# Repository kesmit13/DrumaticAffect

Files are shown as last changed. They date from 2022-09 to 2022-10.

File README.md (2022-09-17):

# Drumatic Affect

The circuit and program described in this project are used to add features to the 
[Digitech SDRUM](https://www.digitech.com/band-creator/SDRUM.html)
pedal, which is a drum machine that has a lot of cool features but seems to be missing some
key functionality for my purposes. The main thing that it is missing is a way to specify
a specific beats per minute. The use cases for the design of the pedal seem to be to use tap
tempo to set the tempo, or to set the tempo when a song is programmed.

I intend to use the pedal to drive the tempo of the song, but I don't program the song slots
with specific songs. Each song slot merely has various beats programmed that can be used in 
various songs. I simply select the set of verse / chorus / bridge beats that work the best for
a song, then set the proper tempo for the song, and start it. I want to be able to set a 
specific tempo that I've determined ahead of time so that the SDRUM unit can keep that exact
tempo rather than setting one on-the-fly with the tap tempo.

Unfortunately, this is the one thing that the SDRUM unit can't do. There is no way to know or set
the exact tempo. You can get in-the-ballpark by using a metronome to set a tempo then trying to
tap that tempo, but it's somewhat in-exact.

The idea came about to have a hardware device send the tap signal rather than a person. This would
give a very exact tempo that could be set simply be dialing in the correct tempo on the device
and having it send emulated taps to the footswitch input. That device is the **Drumatic Affect**.
I came across [another project](https://www.instructables.com/Arduino-Metronome/) that had some 
overlap, started with that and continued to modify it until it fit the new purpose.

## Requirements

I had a pretty long list of requirements for a drum machine that would fit my needs. I tried out
many different solutions and nothing existed that could do everything I wanted. Here is a 
comparison table of many possible solutions.

| Feature | SDRUM + Drumatic Affect | SDRUM | Rock Drummer App | Beat Buddy | Alesis SR-16 | Drum Tracks |
|---|---|---|---|---|---|---|
| Battery powered | yes* | yes*  | yes | yes* | yes* | yes |
| Song selector in arm's reach | yes (with stand) | no* | yes (with stand) | no | yes (with stand) | yes |
| Able to set specific tempo | yes | no | yes | yes | yes | yes |
| Direct access to song parts | yes | yes*  | yes/no | no | yes (only 2) | no |
| Start and stop with footswitch | yes | no* | yes | yes | yes | yes |
| Fills | yes | yes | yes | yes | yes | no |
| Easily programmable | yes | yes | no | yes | no | no |
| Programs beat patterns not just songs | yes | yes | yes | no | yes | no |
| Fast setup at gigs | yes | yes | no | yes | yes | yes |
| Count-in | yes | yes | yes | yes | no | yes |
| Mute on-demand | yes | yes | no | no | no | no |

Some of the requirements are marked with exceptions. Such as the battery powered requirement can be filled 
with a 9v guitar effect pedal battery pack on most devices. The SDRUM does have many of the requirements, 
but some can not be filled at the same time depending on which footswitch mode you use.

## Schematic

The schematic for the Drumatic Affect device is shown below.

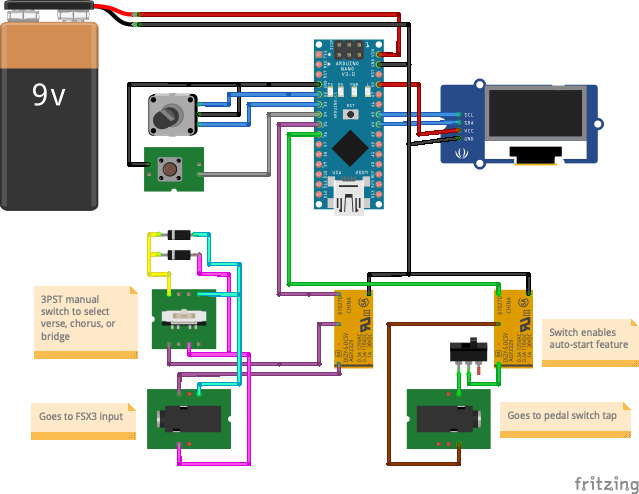
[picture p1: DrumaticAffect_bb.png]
Schematic diagram


This circuit includes two relays driven by an Arduino Nano and the code in this repository.
The first relay is used to send the tap signal to the FSX3 footswitch input. A 2P3T switch can
be used to select which song part to select. This requires the pedal to be in **Direct Part**
mode which allows you to select the verse, chorus, and bridge directly using each of the three
buttons on the FSX3 switch. You can also select the chorus pole of the switch and run the 
pedal in the **Table Top** mode.

The second relay is trickier to use because it requires modifying the pedal (and voiding the
warranty). It is connected to the footswitch on the pedal itself. This requires you to open
the pedal and add leads to the two solder points on the footswitch sub-board and run those
leads to the second relay in this circuit. This relay is used to auto-start a song as soon
as the tempo is set, so it is optional if you can start the song manually after setting the
tempo.

The rest of the circuit is fairly straightforward. There is a rotary encoder with a push button 
switch (shown as two separate components in this diagram). The rotary encoder is used to select
the tempo, then pushing the switch sends three "taps" to the FSX3 input to select the song
part and set the tempo. The second relay then sends a signal to the pedal to start the song.

I did find that cheap rotary encoders are terribly noisy and you'll get stray signals on both
the rotary switch as well as the push button switch; and even worse, you'll get stray signals
on the push button switch while using the rotary switch. I ended up buying [rotary encoders
with built-in debouncing](https://www.tindie.com/products/fabteck/24-steps-rotary-encoder-and-debouncing-circuit/)
(as well as using debouncing in the software).

### Parts List

* Arduino Nano
* Rotary encoder with push-button switch
* 128X64 OLED LCD Display
* 2 - 5V relays
* 2 - 1N4001 diodes
* 2P3T rotary switch
* SPST toggle switch

## What's up with the name?

The word "drumatic" is a play on "automatic drum". The word "affect" is used because it's 
effect pedal, but this device causes the change, it doesn't respond to the change, so "affect"
seems like a better description of it's behavior than "effect". And, of course, the whole
name is a play on the phrase "dramatic effect".

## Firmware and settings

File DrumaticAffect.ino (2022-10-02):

//
// Drumatic Affect
//
// This code is for a device that drives a Digitech SDRUM pedal in order
// to set a specific tempo, select the song part to start with and
// optionally start the song. This is done by driving relays that emulate
// the pedals on a footswitch. One relay drives a pedal that duplicates
// the footswitch on the pedal itself. The other relay sends signals to
// the FSX3 input.
//
// This code is based on the code at https://www.instructables.com/Arduino-Metronome/.
// Metronome, Leading Accent, Visual&Audible Tact - 2019 Peter Csurgay
//
#include <TimerOne.h>
#include <Wire.h>
#include <Adafruit_GFX.h>
#include <Adafruit_SSD1306.h>
#include <Fonts/FreeMonoBoldOblique12pt7b.h>
#include <DFPlayerMini_Fast.h>
#include <SoftwareSerial.h>
#define SCREEN_WIDTH 128
#define SCREEN_HEIGHT 64
#define OLED_RESET -1 // Reset pin # (or -1 if sharing Arduino reset pin)
Adafruit_SSD1306 display(SCREEN_WIDTH, SCREEN_HEIGHT, &Wire, OLED_RESET);
#define ROTARY_PIN_A 2
#define ROTARY_PIN_B 3
#define ROTARY_BUTTON_PIN 4
#define TAP_TEMPO_RELAY_PIN 5
#define START_DRUMS_RELAY_PIN 6
#define PEDAL_TIP_PIN 7
#define PEDAL_RING_PIN 8
#define NUM_COUNTS_PIN_1 9 
#define AUDIO_RX 10
#define AUDIO_TX 11
#define NUM_COUNTS_PIN_2 12
#define ONBOARD_LED 13
#define TEMPO_LED_PIN_1 14 // A0
#define TEMPO_LED_PIN_2 15 // A1
#define TEMPO_LED_PIN_3 16 // A2
#define TEMPO_LED_PIN_4 17 // A3
#define ACCENT_PIN_1 A6
#define ACCENT_PIN_2 A7
#define IDLE_11 0
#define SCLK_01 1
#define SCLK_00 2
#define SCLK_10 3
#define SDT_10 4
#define SDT_00 5
#define SDT_01 6

int state = IDLE_11;
volatile int tempoSet = 0;
volatile int drumsStarted = 0;
volatile int doTaps = -1;
volatile int beat = 0;
volatile int pedalStart = 0;
volatile int autoStart = 1;
volatile int invertDisplay = 0;
volatile int repeatPlay = 0;
int bpm = 90;
int period = 200;
int curVal = 0;
int prevVal = 0;

unsigned long lastChangeTime = 0;
unsigned long changeDelay = 100;

int buttonState;             // the current reading from the input pin
int lastButtonState = LOW;   // the previous reading from the input pin

// the following variables are unsigned longs because the time, measured in
// milliseconds, will quickly become a bigger number than can be stored in an int.
unsigned long lastDebounceTime = 0;  // the last time the output pin was toggled
unsigned long debounceDelay = 50;   // the debounce time; increase if the output flickers

SoftwareSerial audioSerial(AUDIO_RX, AUDIO_TX); // RX, TX

int volume = 30;  // 0 - 30

DFPlayerMini_Fast audio;

void setup() {
  pinMode(TAP_TEMPO_RELAY_PIN, OUTPUT);
  pinMode(START_DRUMS_RELAY_PIN, OUTPUT);
  pinMode(ROTARY_PIN_A, INPUT_PULLUP);
  pinMode(ROTARY_PIN_B, INPUT_PULLUP);
  pinMode(ROTARY_BUTTON_PIN, INPUT_PULLUP);
  pinMode(PEDAL_TIP_PIN, INPUT_PULLUP);
  pinMode(PEDAL_RING_PIN, INPUT_PULLUP);
  pinMode(NUM_COUNTS_PIN_1, INPUT_PULLUP);
  pinMode(NUM_COUNTS_PIN_2, INPUT_PULLUP);
  pinMode(ACCENT_PIN_1, INPUT_PULLUP);
  pinMode(ACCENT_PIN_2, INPUT_PULLUP);
  pinMode(TEMPO_LED_PIN_1, OUTPUT);
  pinMode(TEMPO_LED_PIN_2, OUTPUT);
  pinMode(TEMPO_LED_PIN_3, OUTPUT);
  pinMode(TEMPO_LED_PIN_4, OUTPUT);

  // Initialize display.
  if(!display.begin(SSD1306_SWITCHCAPVCC, 0x3C)) { // Address 0x3D for 128x64
    Serial.println("No display");
    while (1);// Don't proceed, loop forever
  }
  display.clearDisplay();
  display.display();
  updateDisplay();

  // Start metronome.
  Timer1.initialize(1000000 * 60 / bpm);
  Timer1.attachInterrupt(tapIt);
  
  Serial.begin(9600);
  while (!Serial);
  Serial.println("Start");

  // Add rotary encoder interrupts.
  attachInterrupt(digitalPinToInterrupt(ROTARY_PIN_A), rotaryCLK, CHANGE);
  attachInterrupt(digitalPinToInterrupt(ROTARY_PIN_B), rotaryDT, CHANGE);

  // Initialize audio card.
  audioSerial.begin(9600);
  audio.begin(audioSerial, false);
  audio.volume(volume);
}

void rotaryCLK() {
  if (digitalRead(ROTARY_PIN_A) == LOW) {
    if (state==IDLE_11) state = SCLK_01;
    else if (state==SCLK_10) state = SCLK_00;
    else if (state==SDT_10) state = SDT_00;
  }
  else {
    if (state==SCLK_01) state = IDLE_11;
    else if (state==SCLK_00) state = SCLK_10;
    else if (state==SDT_00) state = SDT_10;
    else if (state==SDT_01) { state = IDLE_11; curVal--; }
  }
}

void rotaryDT() {
  if (digitalRead(ROTARY_PIN_B) == LOW) {
    if (state==IDLE_11) state = SDT_10;
    else if (state==SDT_01) state = SDT_00;
    else if (state==SCLK_01) state = SCLK_00;
  }
  else {
    if (state==SDT_10) state = IDLE_11;
    else if (state==SDT_00) state = SDT_01;
    else if (state==SCLK_00) state = SCLK_01;
    else if (state==SCLK_10) { state = IDLE_11; curVal++; }
  }
}

void updateDisplay() {
    display.clearDisplay();
    display.setFont(&FreeMonoBoldOblique12pt7b);
    display.setTextSize(2);
    display.setTextColor(SSD1306_WHITE);
    display.setCursor((bpm >= 100) ? 18 : 33, 45);
    display.print(bpm);
    display.display();
}

int numTaps() {
  int pin_1 = digitalRead(NUM_COUNTS_PIN_1) == LOW;
  int pin_2 = digitalRead(NUM_COUNTS_PIN_2) == LOW;
  return (pin_2) ? 6 : (pin_1) ? 4 : 3;   
}

int whichLED() {
  int n = numTaps();
  if (n == 4) {
    if (beat == 3) return TEMPO_LED_PIN_4;
    if (beat == 2) return TEMPO_LED_PIN_3;
    if (beat == 1) return TEMPO_LED_PIN_2;
    return TEMPO_LED_PIN_1;
  }
  else if (n == 3) {
    if (beat == 2) return TEMPO_LED_PIN_3;
    if (beat == 1) return TEMPO_LED_PIN_2;
    return TEMPO_LED_PIN_1;
  }
  else if (n == 6) {
    if (beat == 5) return TEMPO_LED_PIN_2;
    if (beat == 4) return TEMPO_LED_PIN_3;
    if (beat == 3) return TEMPO_LED_PIN_4;
    if (beat == 2) return TEMPO_LED_PIN_3;
    if (beat == 1) return TEMPO_LED_PIN_2;
    return TEMPO_LED_PIN_1;
  }
}

int whichAccent() {
  bool a1 = analogRead(ACCENT_PIN_1) < 20;
  bool a2 = analogRead(ACCENT_PIN_2) < 20;
  return (a1 && a2) ? 5 : (a2) ? 4 : 3;
}

void tapIt() {
  int flipDrumsRelay = 0;

  // Determine the LED pin based on the beat number.
  int ledPin = whichLED();

  // Light up current beat LED.
  digitalWrite(ledPin, HIGH);

  // If we used the pedal to start, do it on beat 1.
  if (beat == 0 && !autoStart && pedalStart) {
    digitalWrite(START_DRUMS_RELAY_PIN, HIGH);
    drumsStarted = 1;
    pedalStart = 0;
    tempoSet = 0;
    autoStart = 1;
    flipDrumsRelay = 1;
  }
  
  // If we're at zero taps and auto-start is enabled, start the drums.
  else if (doTaps == 0 && autoStart) {
    digitalWrite(START_DRUMS_RELAY_PIN, HIGH);
    invertDisplay = 1;
    drumsStarted = 1;
    pedalStart = 0;
    flipDrumsRelay = 1;
  }
  
  // If we're still counting taps, trigger the tap relay and external tap tempo signal.
  else if (doTaps > 0) {
    digitalWrite(TAP_TEMPO_RELAY_PIN, HIGH);
  }

  // Light beat LED and play click if we're still in the count-in.
  if (repeatPlay) {
    Serial.print("Play "); Serial.print(repeatPlay); Serial.println("");
    audio.play(repeatPlay);
  }
  else if (doTaps > 0) {
    audio.play(1);
  }
  
  delay(10000);

  // If we activated the start-drums relay, deactivate it.
  if (flipDrumsRelay) {
    digitalWrite(START_DRUMS_RELAY_PIN, LOW);
    doTaps--;
  }
  
  // If we are sending taps, turn the tap relay off now.
  else if (doTaps > 0) {
    digitalWrite(TAP_TEMPO_RELAY_PIN, LOW);
    doTaps--;
  }

  // Update beat number.
  beat = (beat + 1) % numTaps();

  // Turn off current beat LED.
  digitalWrite(ledPin, LOW);
}

int digitalReadDebounce(int pin) {
  // Read a digital signal while attempting to debounce the switch.
  int next = 0;
  int out = digitalRead(pin);
  delay(5);
  while ((next = digitalRead(pin)) != out) {
    delay(5);
    out = next;
  }
  return out;
}
 
void loop() {
  // Flip screen back after teaching taps.
  if (invertDisplay) {
    invertDisplay = 0;
    display.fillScreen(SSD1306_INVERSE);
    display.display();
  }

  //
  // Pedals
  //
  
  // Try to debounce the switch (don't use digitalReadDebounce because we want to interlace the reads).
  bool pedalTip = digitalRead(PEDAL_TIP_PIN) == LOW;
  bool pedalRing = digitalRead(PEDAL_RING_PIN) == LOW;
  delay(5);
  pedalTip = pedalTip && digitalRead(PEDAL_TIP_PIN) == LOW;
  pedalRing = pedalRing && digitalRead(PEDAL_RING_PIN) == LOW;

  // Start / stop pedal
  if (pedalTip && !pedalRing) {
    Serial.println("Start / Stop");
    
    // If a tempo has been set and we hit this pedal momentarily, 
    // start the beat at the next LED blink. This should start the 
    // drums in sync with the blinking LED.
    if (tempoSet && !drumsStarted && !autoStart) {
        tempoSet = 0;
        pedalStart = 1;
        delay(500);
    } 
    else {
      digitalWrite(START_DRUMS_RELAY_PIN, HIGH);
      delay(200);
      // Hold until pedal is released.
      while (digitalReadDebounce(PEDAL_TIP_PIN) == LOW) {
        delay(50);
      }
      digitalWrite(START_DRUMS_RELAY_PIN, LOW);
      delay(100);
    }
  } 

  // Kick pedal
  else if (!pedalTip && pedalRing) {
    Serial.println("Play kick");
    audio.play(2);
    delay(100);
    // Hold until pedal is released.
    while (digitalReadDebounce(PEDAL_RING_PIN) == LOW) {
      delay(50);
      repeatPlay = 2;
    }
    repeatPlay = 0;
    delay(50);
  }

  // Accent pedal
  else if (pedalTip && pedalRing) {
    int track = whichAccent();
    Serial.print("Play accent "); Serial.println(track);
    audio.play(track);
    delay(100);
    // Hold until pedal is released.
    while (digitalReadDebounce(PEDAL_TIP_PIN) == LOW) {
      delay(50);
      repeatPlay = track;
    }
    repeatPlay = 0;
    delay(50);
  }

  //
  // Tempo knob
  //
  
  int reading = digitalRead(ROTARY_BUTTON_PIN);

  if (reading != lastButtonState) {
    lastDebounceTime = millis();
  }  
  else if ((millis() - lastDebounceTime) > debounceDelay) {
    if (reading != buttonState) {
      buttonState = reading;
      // If a second press is detected during the taps, disable autoStart.
      if (doTaps >= 0 && buttonState == LOW) {
        autoStart = 0;
        invertDisplay = 1;
      }
      // If a press is detected, start the taps.
      else if (buttonState == LOW) {
        tempoSet = 1;
        pedalStart = 0;
        beat = 0;
        autoStart = 1;
        drumsStarted = 0;
        doTaps = numTaps();
        display.fillScreen(SSD1306_INVERSE);
        display.display();
        Timer1.restart();
        delay(100);
      }
    }
  }

  lastButtonState = reading;

  if (doTaps == -1 && curVal > prevVal) {
    //Serial.println('up');
    unsigned long tm = millis();
    lastButtonState = HIGH;
    lastDebounceTime = tm + debounceDelay * 4;
    bpm += ((tm - lastChangeTime) > changeDelay) ? 1 : 5;
    lastChangeTime = tm;
    if (bpm > 240) bpm = 10;
    updateDisplay();
    pedalStart = 0;
    tempoSet = 0;
    Timer1.setPeriod(1000000 * 60 / bpm);
  } 
  else if (doTaps == -1 && curVal < prevVal) {
    //Serial.println('down');
    unsigned long tm = millis();
    lastButtonState = HIGH;
    lastDebounceTime = tm + debounceDelay * 4;
    bpm -= ((tm - lastChangeTime) > changeDelay) ? 1 : 5;
    lastChangeTime = tm;
    if (bpm < 10) bpm = 240;
    updateDisplay();
    pedalStart = 0;
    tempoSet = 0;
    Timer1.setPeriod(1000000 * 60 / bpm);
  }
  
  prevVal = curVal;
}

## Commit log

2022-09-07 Add schematic
    [DrumaticAffect.fzz]
2022-09-17 Start of v2
    [DrumaticAffect.fzz]
2022-10-02 Major refactoring; use interrupt for all taps and automated drum hits; auto-start disabled by rotary switch button; when auto-start disabled, pressing start button starts beat at next beat 1
